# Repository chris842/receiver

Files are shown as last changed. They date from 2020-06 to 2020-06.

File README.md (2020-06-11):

# SDR Project
* Software-defined radio receiver, Engineering Electronics ii, Spring 2020
* Partners: Chrisner Garcesa and Andrew Nascimento

## Goal
The goal of this project was to design the schematic for a radio receiver and implement it on a PCB.

## Specifications
The specific goals to achieve given by our professor were as follows:  
* Minimum discernible signal of less than 1uV  
* Image rejection of over 48kHz of band greater than 30dB  
* Tunable range of frequencies greater than 48kHz  
* Band frequency greater than 540kHz  
* Spurious signals below 10uV  

Additional equipment we would have at our disposal would be the Arduino Nano Every

## Block Diagram
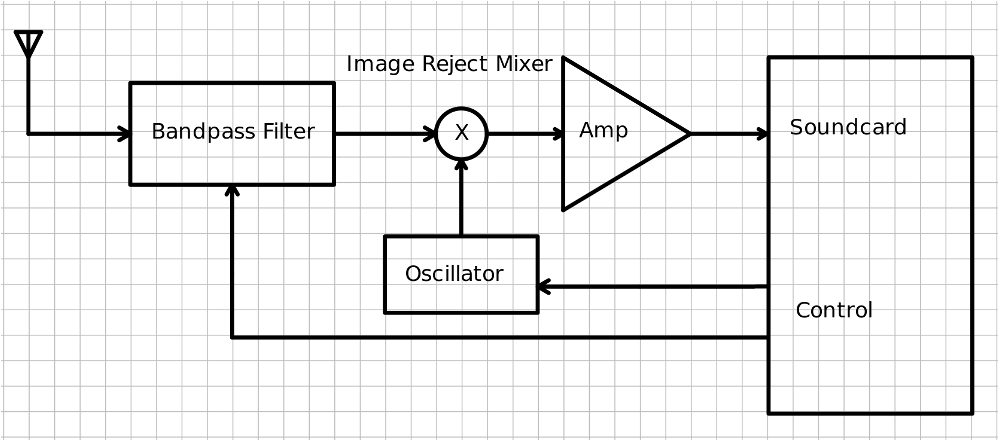
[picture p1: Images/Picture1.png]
Block Diagram
  
This is the general design we would follow in order to have a simple, working receiver. It would be our choice on how to implement each element of this design, however we often chose solutions that the professor suggested or other classmates were using as well, but adapted to our needs.

## Schematic
Here is a breakdown of our schematic:

### Bandpass-filter
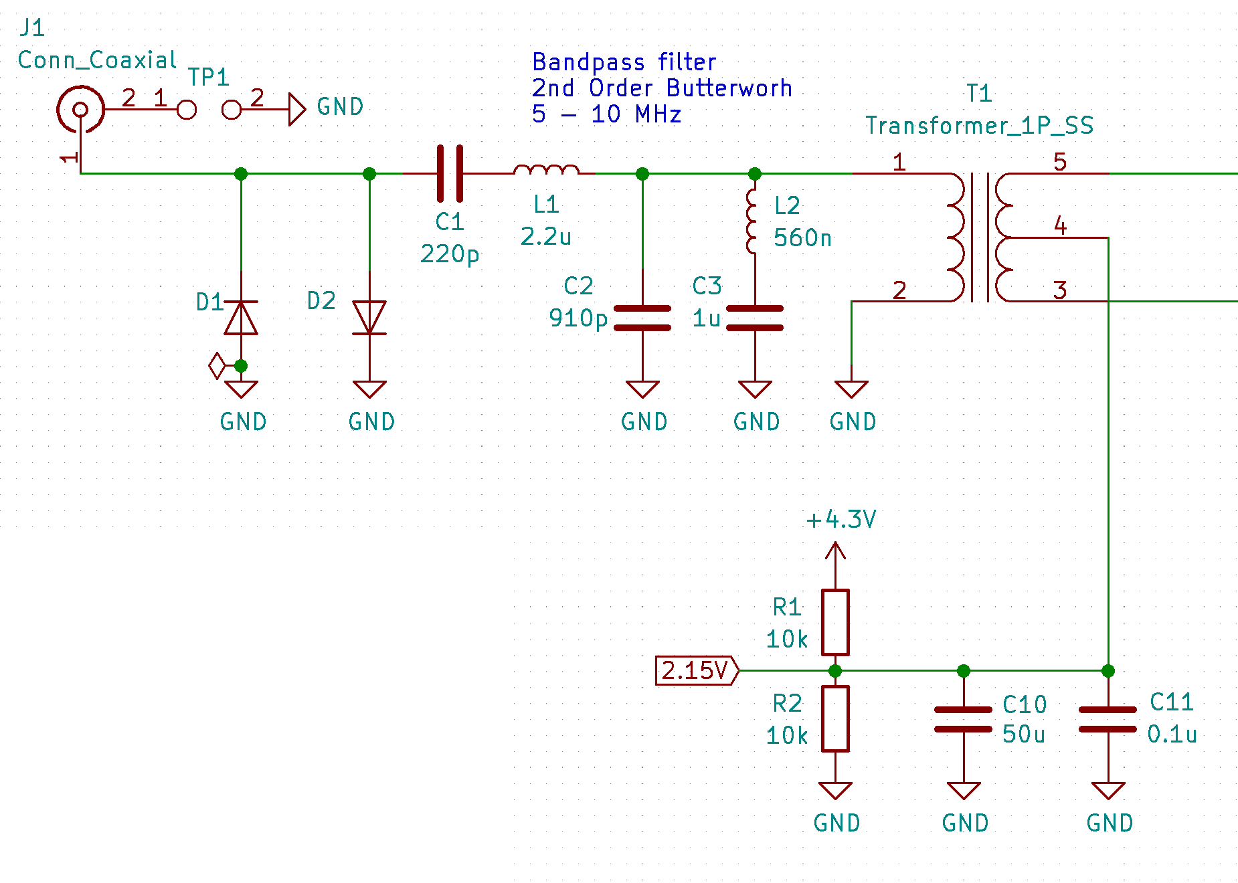
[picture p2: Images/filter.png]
Butterworth Filter
  
This part of the schematic is to filter our choice of frequencies to capture. We chose a range of 5-10MHz to listen to, so the incoming frequency is filtered through a 2nd order Butterworth filter. The transformer at the end sets the DC operating point of the incoming signal at 2.15V.

### Mixer
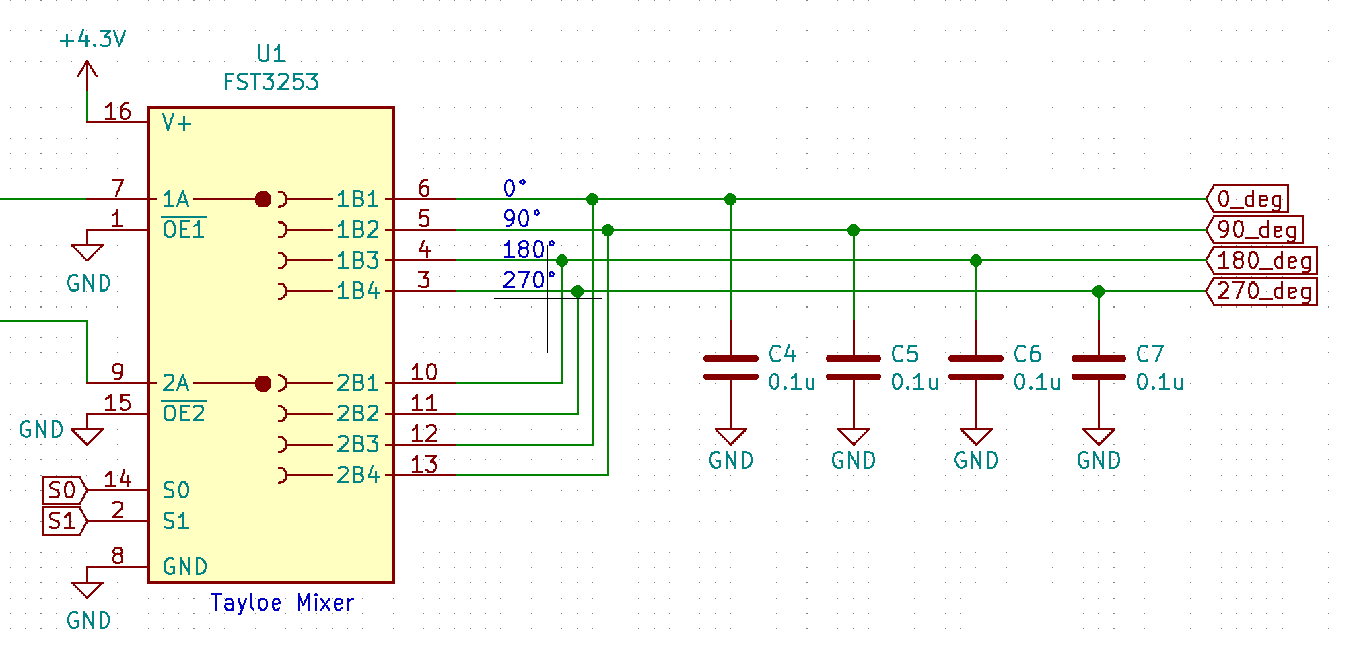
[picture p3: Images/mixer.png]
Tayloe Mixer
  
[This mixer was designed by Dan Tayloe]
(https://www.google.com/url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)

It is simple to implement, is low noise, and allows the bandwidth to be adjusted. The first part of this circuit, the multiplexer, breaks the incoming signal into four outputs, at 0˚, 90˚, 180˚, and 270˚. Then the op-amp, shown below, inverts the redundant sections of the wave and diffferentiates them with their same-phase pair, then outputs two signals, which he calls the In-Phase and Quadrature signals. The op-amp filters the output to the audio-frequency range of up to 25kHz.  
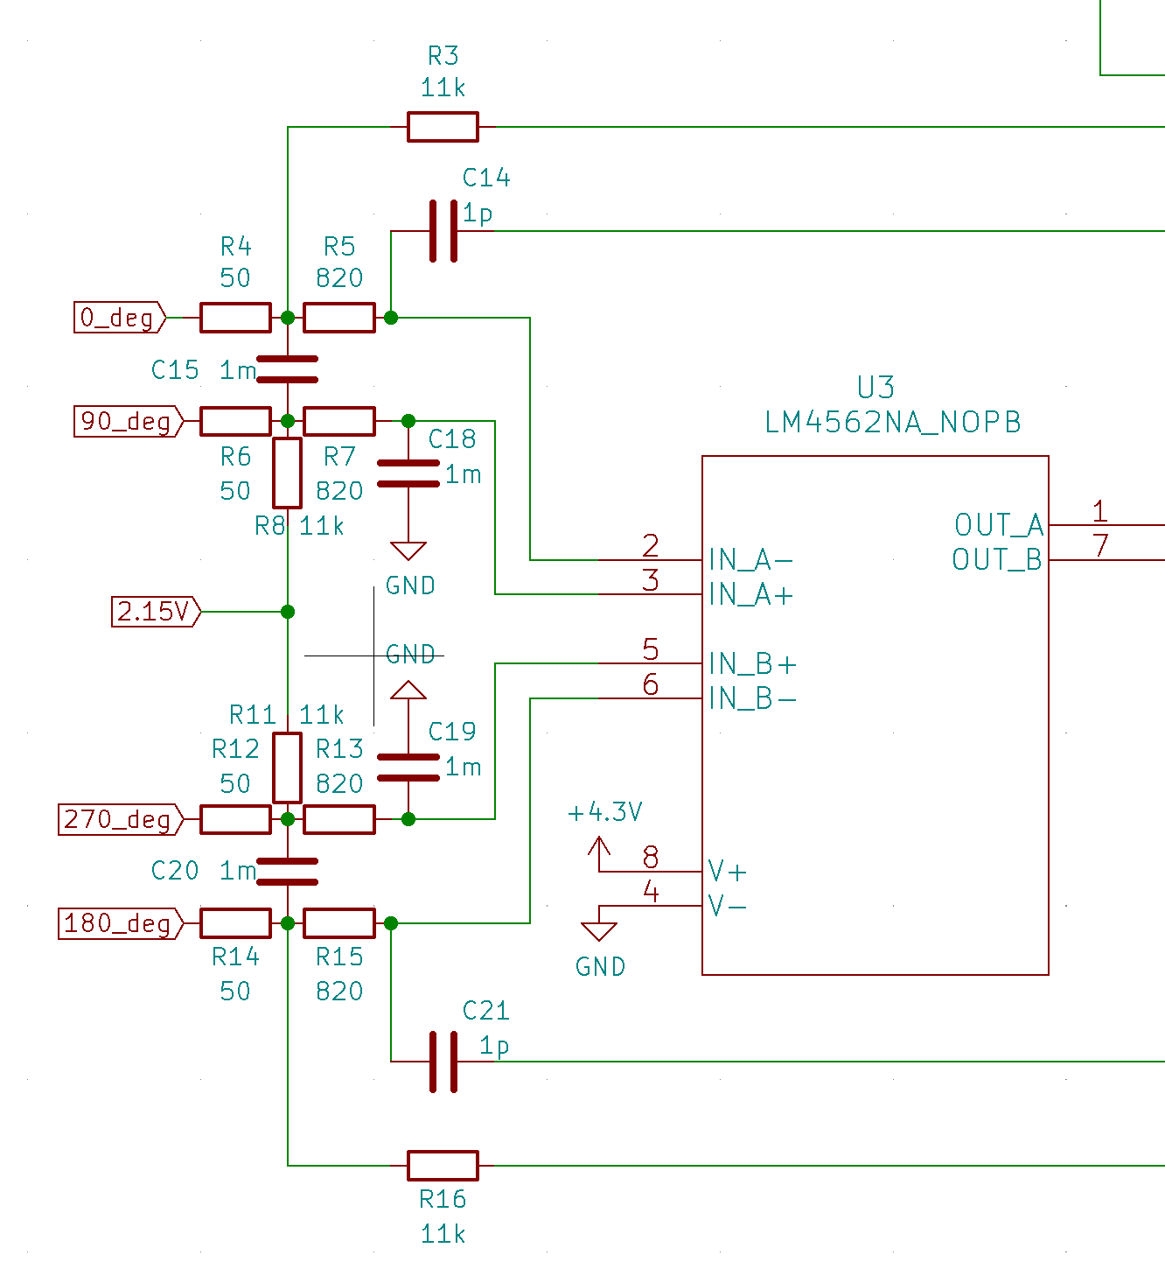
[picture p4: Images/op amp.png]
Op Amp


### Clock Generator and Johnson Counter
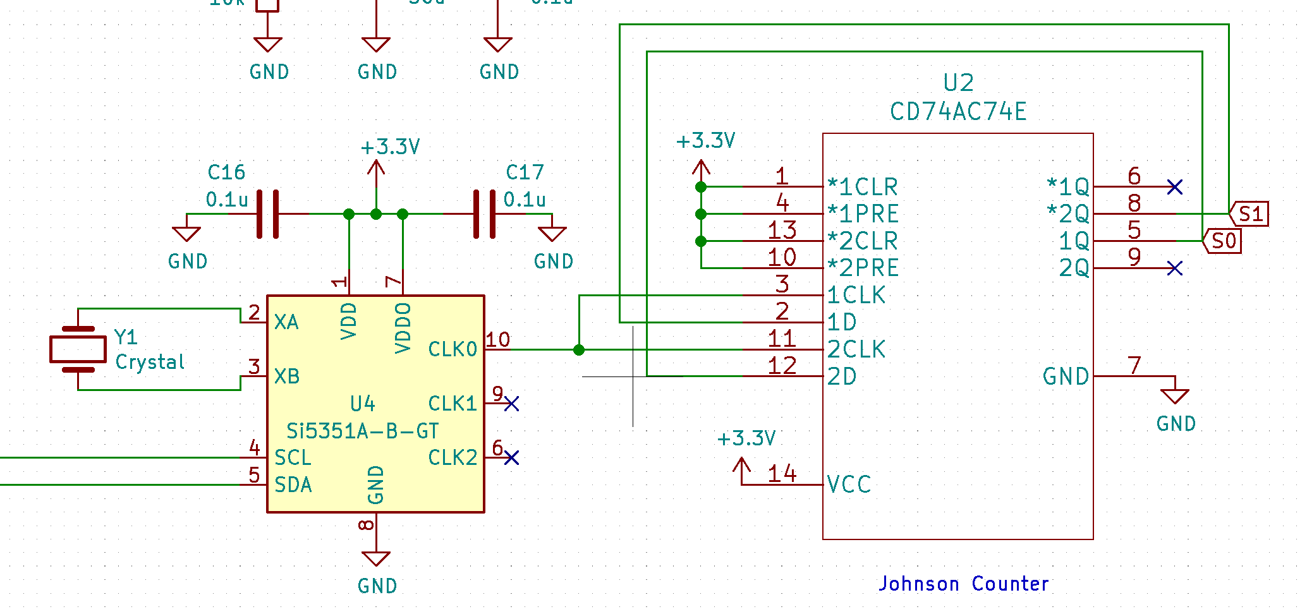
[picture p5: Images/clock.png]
Clock
  
The purpose of this circuit is to drive the multiplexer used in the Tayloe Mixer. The Johnson Counter arrangement of the flip-flops is used to activate the multiplexer switches, selecting the portion of the incoming wave to be inverted and differentiated. The switching frequency is set by an Arduino program.

### Voltage Smoother
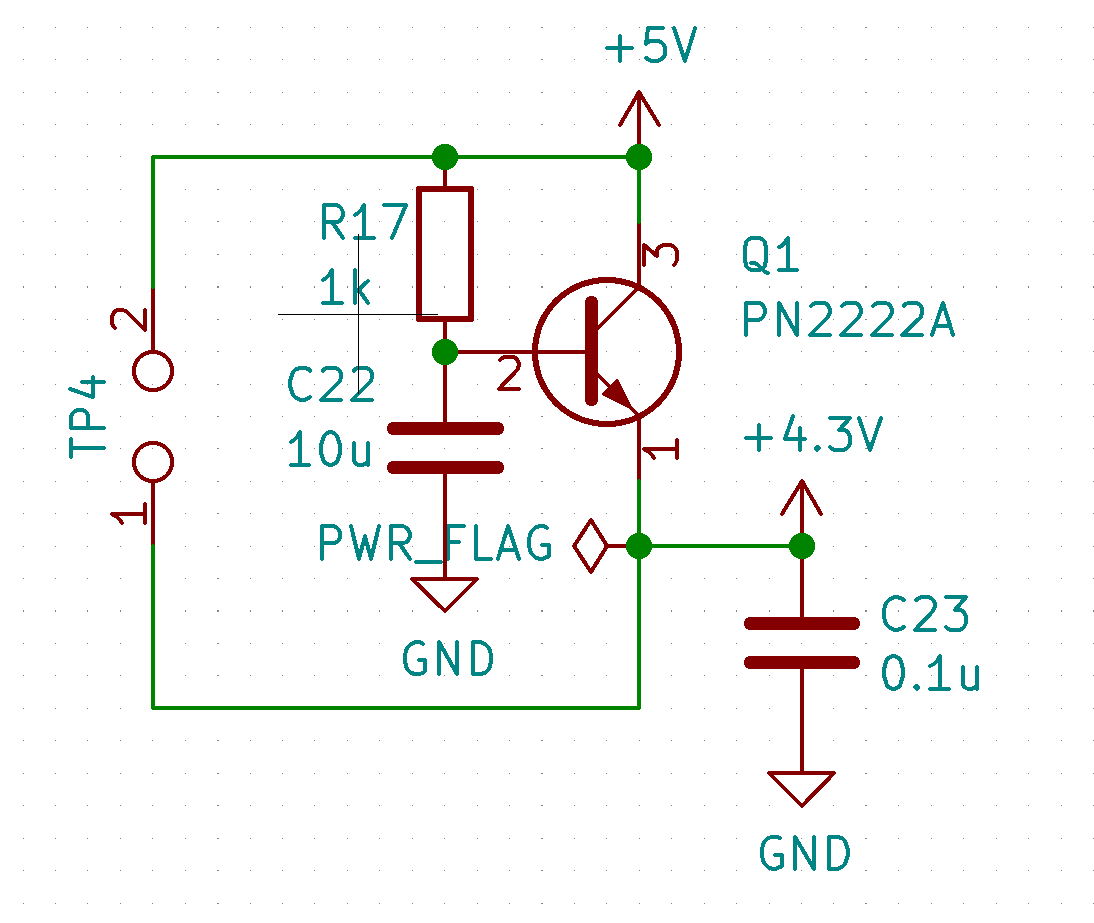
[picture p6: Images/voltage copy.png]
Voltage
  

Dr. Frohne designed this section of the schematic to provide a stable, ripple-free voltage source. It takes 5 volts from the Arduino and powers the multiplexer, op amp, and DC bias circuit.

### Complete Schematic
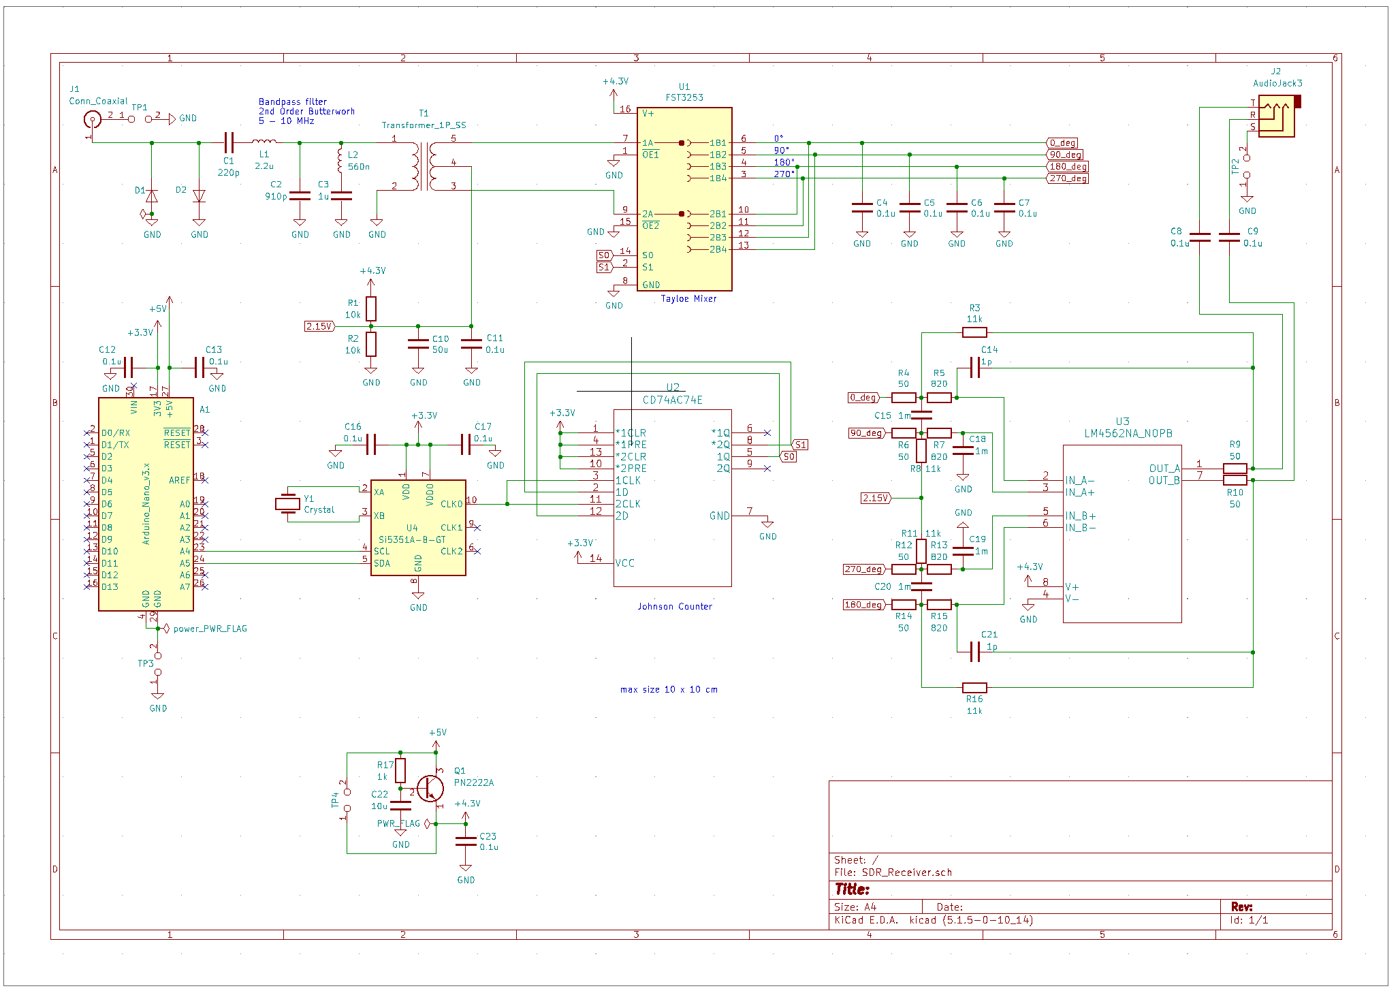
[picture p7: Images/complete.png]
Schematic
  

## PCB
### Board Schematic
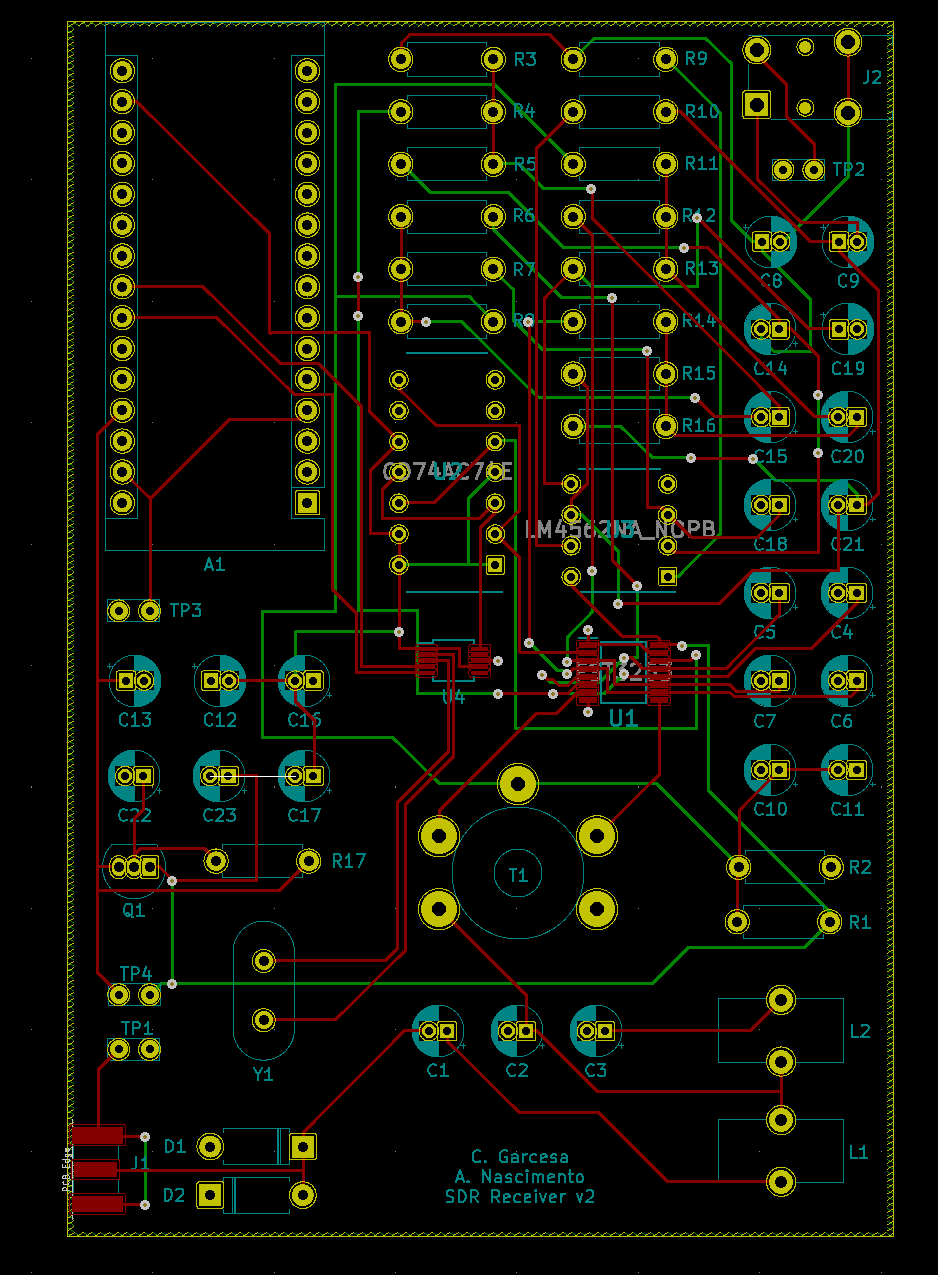
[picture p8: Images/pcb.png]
PCB
  
PCB design in KiCAD

### Board Render
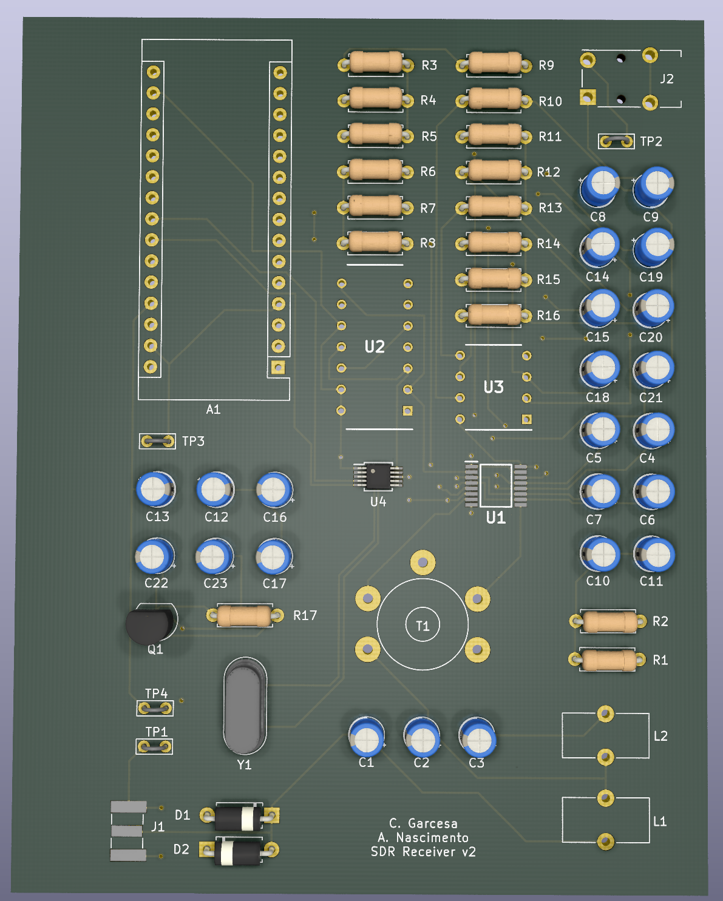
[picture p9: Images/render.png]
render
  

### Assembled Board
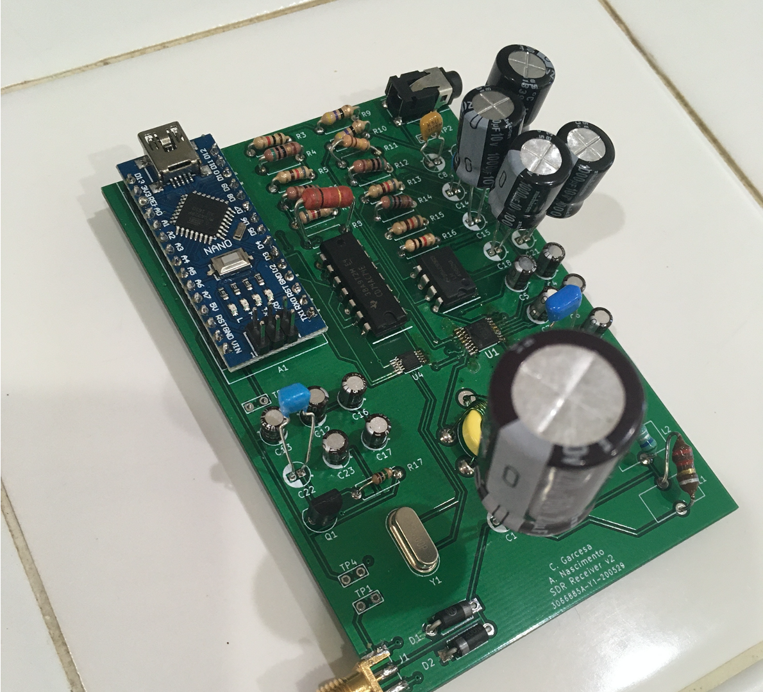
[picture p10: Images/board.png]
board
  

## Tests & Results
### Bandpass Filter
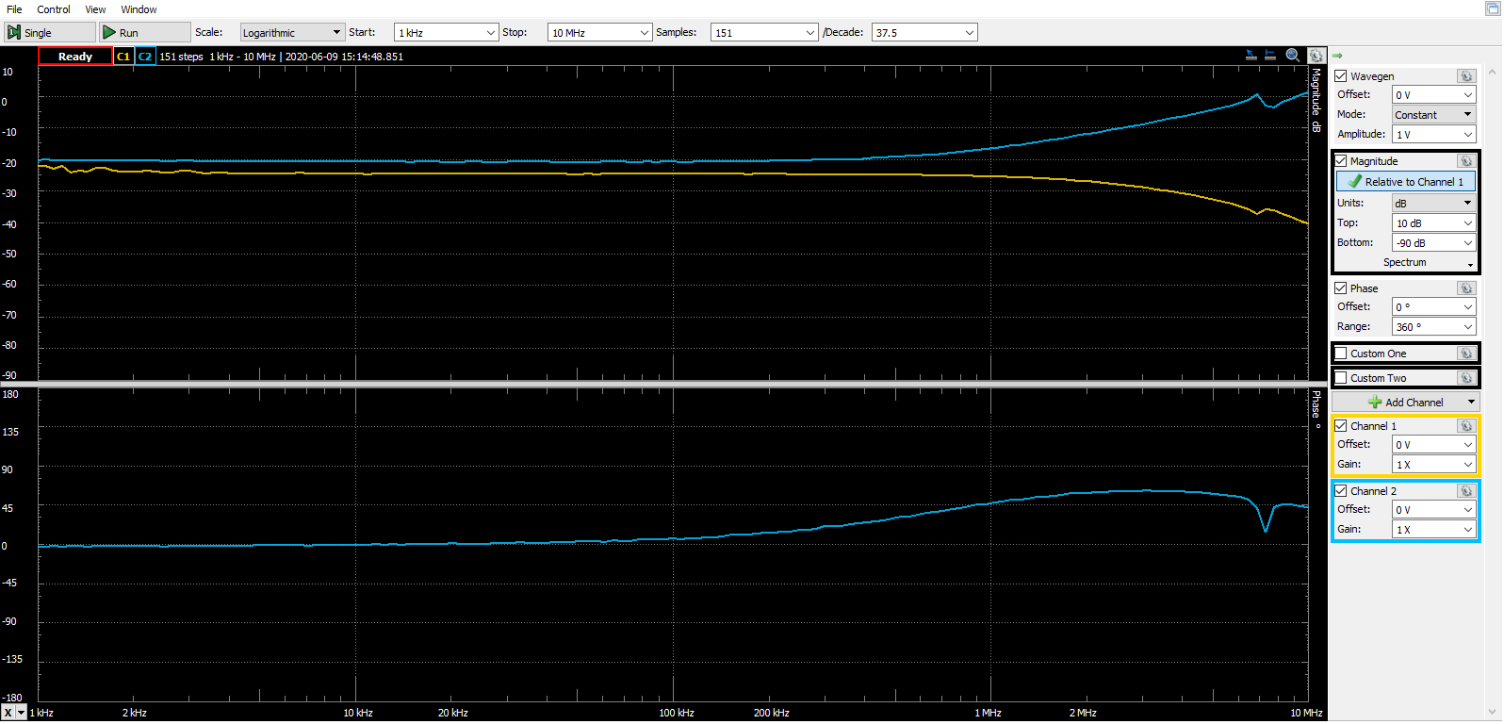
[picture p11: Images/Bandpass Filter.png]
bandpass
  
The bandpass filter seems to work as expected. There is attenuation up to around 5MHz, where our band begins. A 500mV test signal was used.

### Transformer
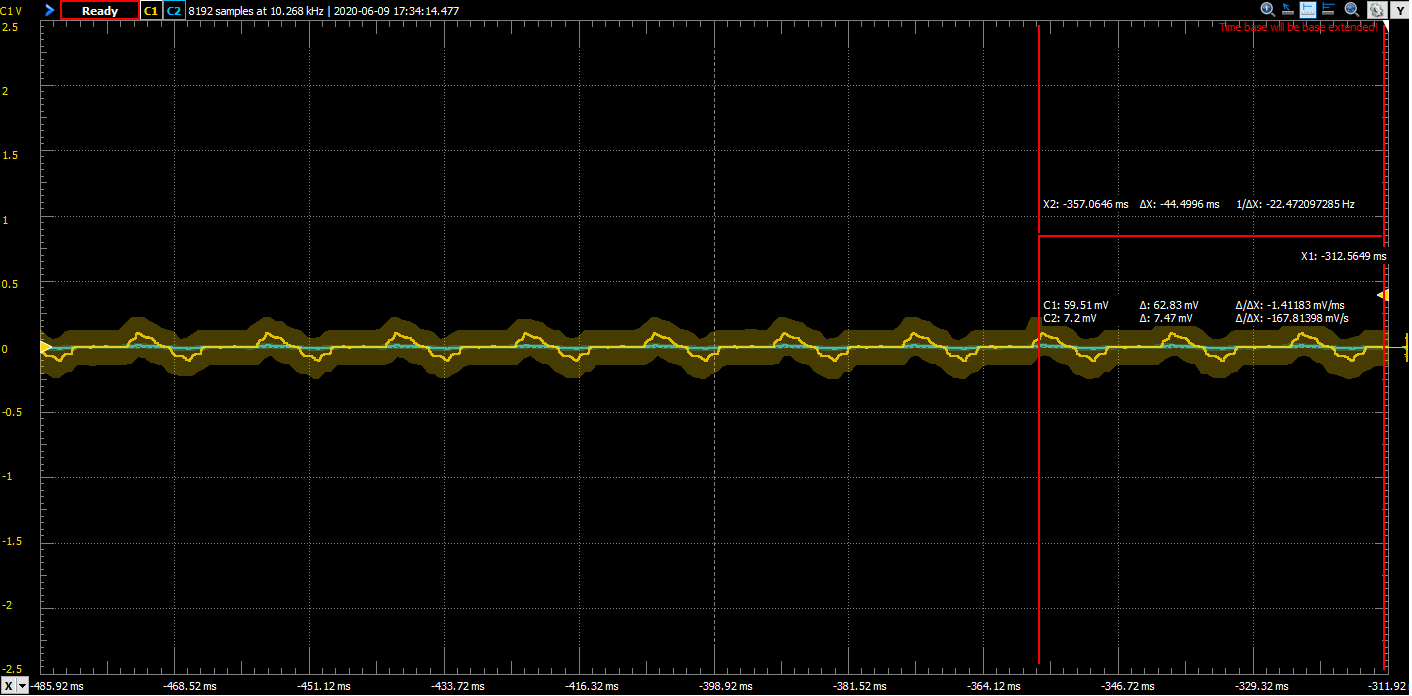
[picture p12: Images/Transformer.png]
transformer
  
Our initial winding configuration seemed to only produce noise. An updated winding configuration is shown further below.

### Tayloe Mixer
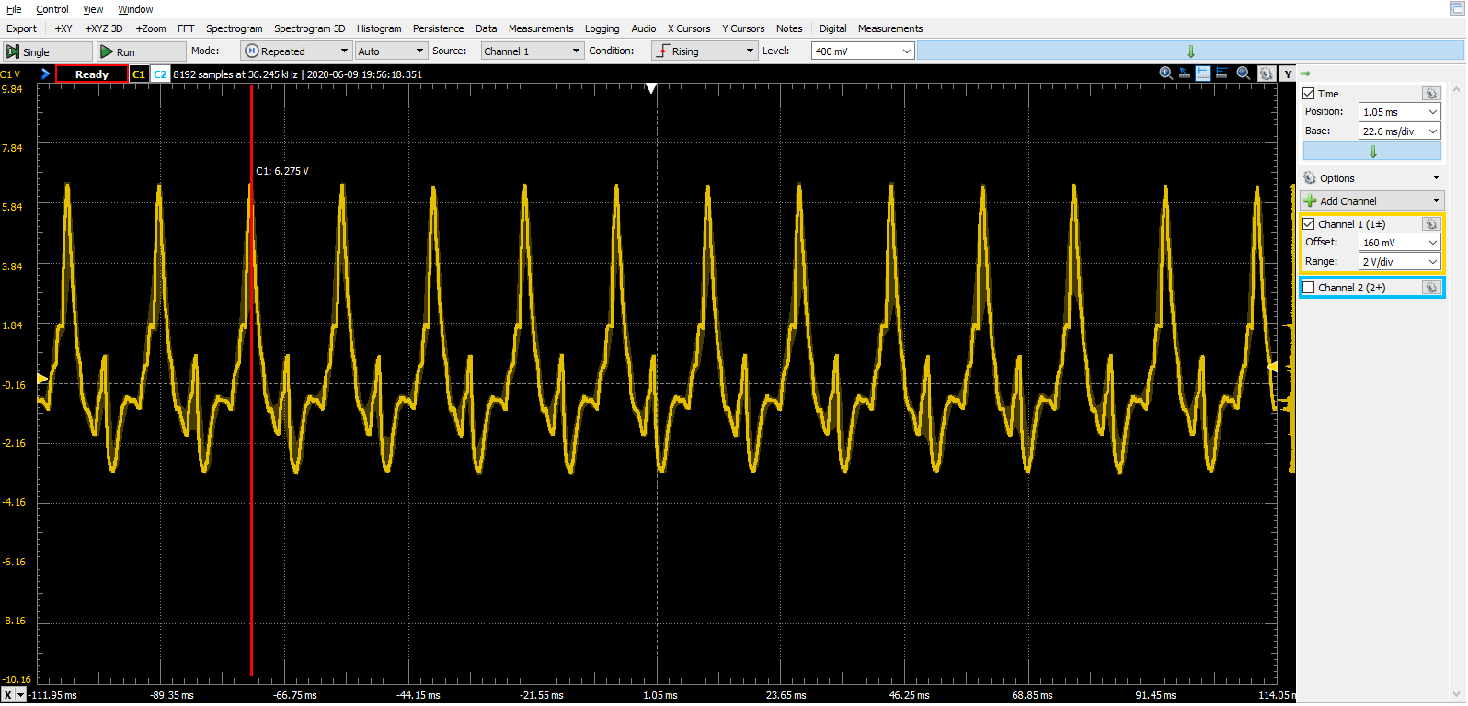
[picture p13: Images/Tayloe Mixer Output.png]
mixer
  
This is not the expected output of the Tayloe mixer. We expected to  a quadrant of a sine wave on each output. Since we cannot verify if the oscillator circuit is working properly, this error may be due to the oscillator.

### Op Amp
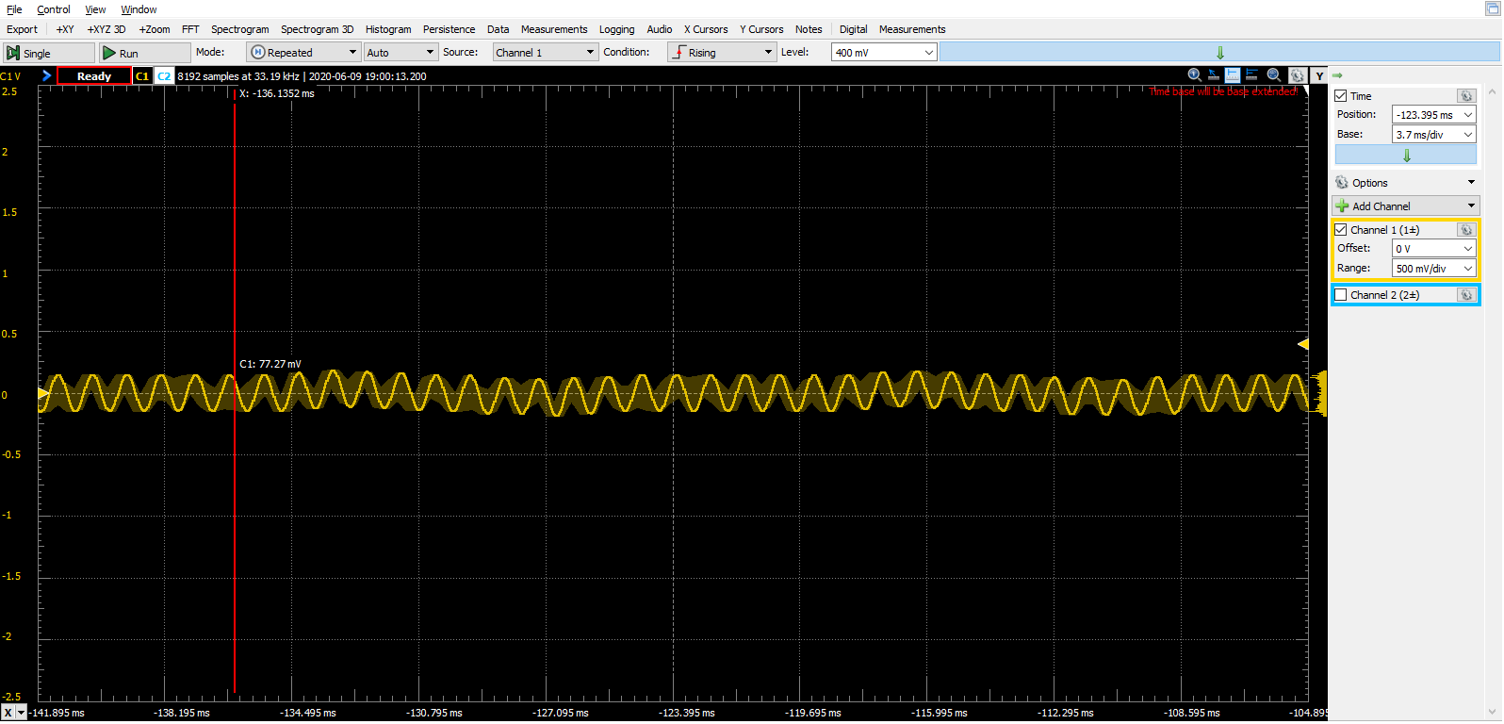
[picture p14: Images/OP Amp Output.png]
op amp
  
The op amp seems to be functioning. We can only verify if it works as intended when the Tayloe mixer is working.

### Arduino & Oscillator
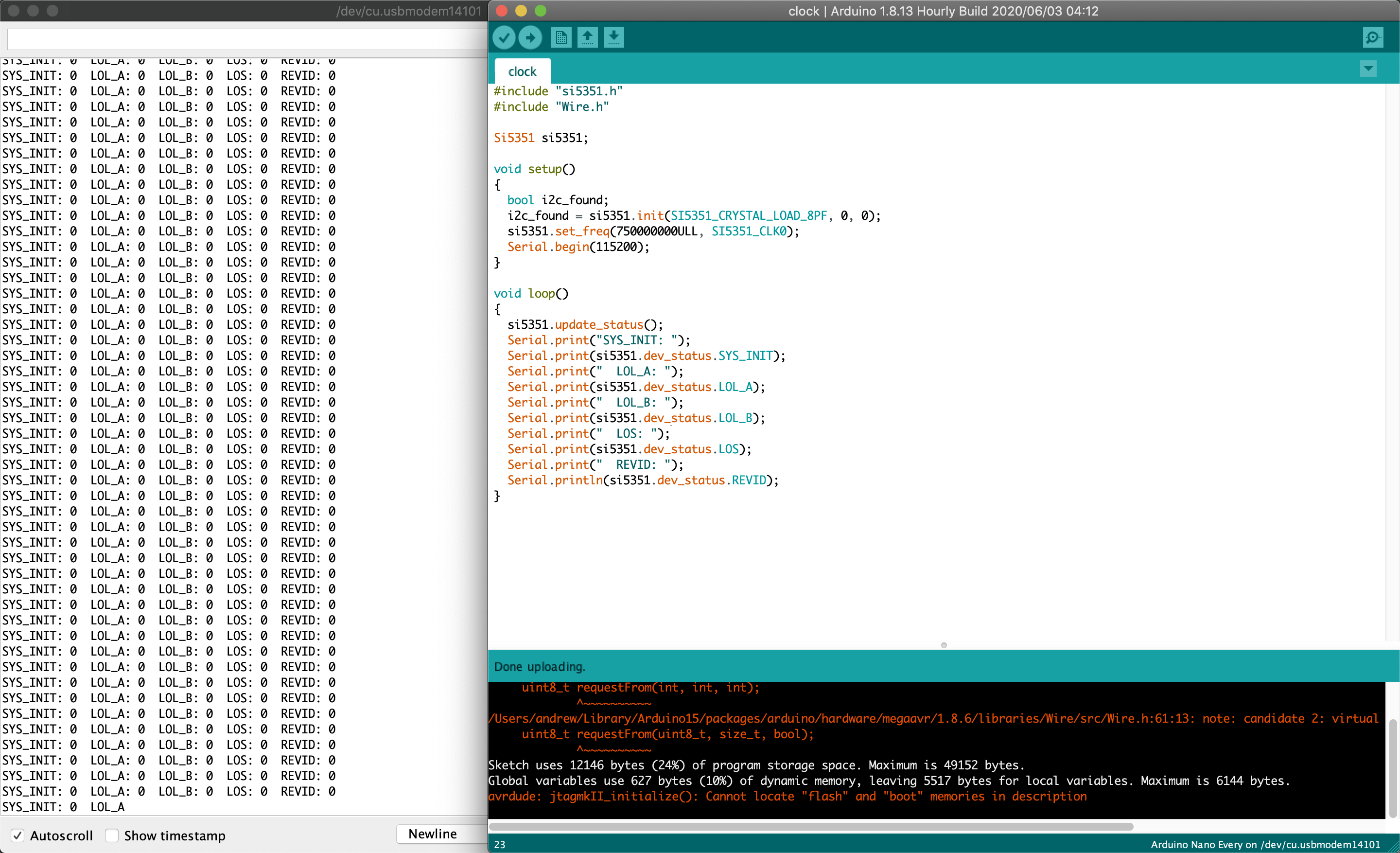
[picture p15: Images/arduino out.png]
arduino
  
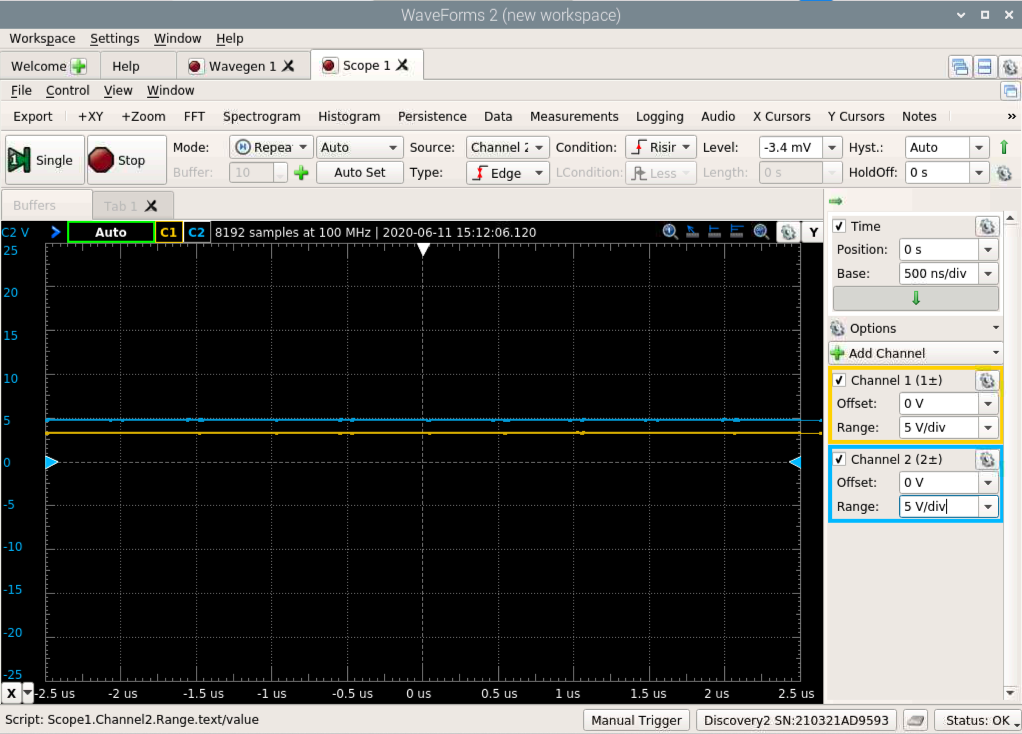
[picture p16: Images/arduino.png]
arduino
  
Arduino 5V and 3V3 signals appear as expected. Gauging by the serial output, the SDR program seems to be working, but we were not able to capture a signal on the SDA and SCL ports.

## Problems & Things to Fix
### Transformer
We tried a different configuration for the transformer, by winding 18 turns on the primary and 18 on the secondary, and placing a center tap from the 2.15V pad to the middle point of the transformer. We were able to capture a clean sine wave at the transformer input, but not the output. 

### Voltage Divider
We were able trace the 4.3V signal up to where it meets R1 at the voltage divider, but we did not see any voltage across R1 or R2. This can explain why the transformer secondary is not working.

### Tayloe Mixer
The Tayloe mixer is likely not working due to the transformer issue. Since 4.3V is being produced, the output is likely due to the lack of signal reaching the mixer.

### Oscillator
We assume the issue with the oscillator is due to the Arduino program, although it seems to be working fine. It may also be due to improperly placing the surface mount IC on the board. 

## Lessons Learned
### PCB Design
We learned how to design a PCB from start to finish using KiCAD.

### Test Points
Having more test points would make debugging the circuit much easier. We did not include enough test points on the board so it was difficult to get measurements in certain places, and that made it harder to narrow down where issues were originating.

### Trial & Error
While it is important to simulate as much as possible so that a working design is achieved when the board is printed, some things were only able to be debugged when we put the circuit together. Simulation also doesn't account for our personal errors and mishaps, so having extra parts for a future project is important in case we damage parts.

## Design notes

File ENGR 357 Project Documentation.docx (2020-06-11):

ENGR 357

SDR Project

Chrisner Garcesa

Andrew Nascimento

June 10, 2020

Project Description

The purpose of this project was to build a software defined radio, to which we decided that it would operate from 5 to 10 MHz. To control the device, we will be using a. Arduino Nano, and we will use a program provided to control the Arduino. We also had to build an attenuator, which would help with the SDR device.

Circuit Description

When looking up circuit designs, there was one that I found that I thought would be helpful. Our design wasn’t entirely based on it, but it helped serve as a guide on how we should go about designing the board. When I went about researching for the project, there was one site (https://www.arrl.org/files/file/Technology/tis/info/pdf/020708qex013.pdf) that I found to be useful. This is where I got the basic layout for the project, and more details will be discussed later on.

Differential Op Amp

Tayloe Mixer

Bandpass Filter

Oscillator

Johnson Counter

Arduino Nano

The signal coming in will have to go through the bandpass filter, to which we decided it should operate around 5 to 10 MHz. In order to get the values to get that range, we used an online calculator (https://rf-tools.com/lc-filter/) to get the desired values. The type of bandpass filter we decided to use was a Buttersworth, series first, 3rd order bandpass filter. For the Tayloe Mixer, there were a couple of other mux’s that we had gone through before getting to the FST3253. When designing this, it should ideally range from 0°, 90°, 180°, and 270°. There was also the oscillator, and to operate that, we used a Si5351, which in turn would be powered by the Arduino nano. Before that, we have the Johnson counter. For this stage, we chose a CD74A74E flip flop. We had originally gone with a different flip flop, but we went with the latter due to it being a bit faster than the original one we chose. The differential Op Amp was something that was implemented later on in the design phase, right before we had to turn the schematic. I had originally had just a low pass filter at the end before the signal went to the audio jack, but Andrew had added the differential op amp to help with the design.

Software

One of the most obvious parts of the board that needed software was the Arduino Nano. For this, we needed to download Arduino IDE and the code we used to test the oscillator and the clock was taken from Frohne’s github (https://github.com/frohro/IQ_SDR/tree/master/Quisk). Other bits of software we used was Python (https://www.python.org/), WaveForms (https://store.digilentinc.com/waveforms-download-only/), and Quisk (https://james.ahlstrom.name/quisk/), which would’ve helped us with testing when our boards were built.

Build Instructions

Due to the nature of this project, the board had to be built in 4 main stages. They can be done in the following order:

1. Bandpass filter
2. Tayloe Mixer
3. Johnson Counter
4. Differential Amplifier

A good place to start though is by soldering on the IC chips, since they are the most difficult to put on the board. I would suggest putting a bit of solder on one of the places where the pins should be, and after it settles, put the IC chip in its place (make sure it’s oriented correctly). Using the soldering iron, heat up the place where the solder is and hold the IC in place. If done correctly, the IC chip should be set in place, and then the rest of the pins can be filled with solder (make sure just to put a little bit and not too much, otherwise the pins may end up being connected together). After the IC’s have been placed in their places, the next thing to do is to build each stage and testing each one separately (however, I made the mistake of not doing that, so testing became a little bit difficult to do, but not impossible. Highly recommended building in stages). After each stage has been built and tested, you can move on to the next one and so on, until each stage has been built.

Test Results

The test results for the project are a bit mixed. There were some components that did work, and there were other areas where it did not work out as intended. One of the things that had worked out as intended was the bandpass filter, which was probably the easiest part to test out. The other stage that had worked out was the differential op amp. When I tested this part, it was recommended that I take out two resistors (R4 and R6), and I hooked up two probes at those resistors and connected a single probe to one of the capacitors at the output. The two probes connected to the resistors were connected to the wave generator, and the single probe should be the one that will measure the output. When I tested this, I had put in a small signal, one that was around 500 mV. For the output, I thought the signal coming out of the capacitors was fairly good, though I will note that the sinewave output was a bit smaller than the input.

What didn’t work was the Tayloe Mixer, the Johnson Counter, the transformer, and the crystal oscillator. When I had tested the transformer, I had connected a probe at the output of the transformer, which could either be pins 5 or 3. I had also placed probes at the beginning of the bandpass filter, which were connected to the two diodes. After running a signal through the bandpass filter and the transformer, the output of the transformer came out to be a bit messy. The output signal somewhat resembled a sine wave, but it looked a bit rough and sporadic. The next thing that I had tested was the Tayloe mixer, and the signal that came out more or less the same as the transformer. I had even tested it separately by placing two probes at the beginning of the Tayloe mixer and measured it at the end, and the signal appeared to be just as messy. The last thing that I had tried testing was the Johnson Counter and the Crystal oscillator. However, this required using the code needed for the Arduino Nano, and the problem with this was the Arduino IDE kept crashing every time I tried opening it (I had tried to install older versions, but those versions also kept crashing on startup). At this point, it was fairly late, so I couldn’t test any further.


Bandpass Filter


Differential Op Amp


Transformer Output


Tayloe Mixer Output

Considerations for future uses

There were a couple of things that I had thought of for trying to fix the device. So far, the only things that I think may work as intended are the Bandpass filter and the Differential Op Amp. However, there is a lot more work to do with the other parts of the board. Here are a couple of ideas on how to fix:

1. Fixing the transformer: the transformer turns ratio may be responsible for this. From how it was built, it was a step-down transformer, so probably changing it to a step-up transformer may help. Another thing that will have to be taken into consideration is the turns ratio. Due to time constraints, I had little time to calculate the turns ratio, so I ended up using an online calculator to determine the turns ratio (the online calculator required input and output impedances, where I needed the output impedance to determine the turns ratio, which I think wasn’t correct).
2. Reconfiguring the Tayloe Mixer and Crystal Oscillator: I also have reason to believe that both these stages would not work out as well, even if the I got the code working for them. Some things that I may do is try to simulate these stages again, but I will try to do it carefully. Another issue may be how I soldered the IC chips. I had soldered these chips by hand, and I had made sure that each pin was not somehow connected. With that said, there may be some pins that are accidentally connected, so I may try a different method of soldering the next time around. Lastly, the crystal oscillator may also potentially be a problem, so I may have a closer look on how to fix that part

Conclusion

After building and testing the board, there are still a lot more things to fix in order to get this thing working. With that said, I will try to work on this more in the future to (hopefully) get it into a working state. One of the stages that I will try to focus a bit more on detail is the Tayloe Mixer and the Johnson counter. I believe these are the more crucial parts of the board, and if I can get this working, I think that it’ll be easier to work with the rest of the board. The other stages and components should be fairly easy to work with, so I’m not too worried about the other stages.

Along with this project, I think that I had learned more about how to use KiCAD and how to design a PCB and what to take into consideration. With this board, there were some parts that were hard to solder on, so knowing that I will have to take into consideration who will be building the board, and how to make it easy as possible to build.

With that said, I will try to work on this project in the future. I think that it’ll be interesting to have this device actually work, and I will try to do more research on how to debug and fix this device.

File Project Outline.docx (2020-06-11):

Chrisner Garcesa

Rob Frohne

ENGR 357L

7 May 2020

Electronics II: Project Outline

1. Have values for resistors and capacitors figured at least before the board arrives
  a. Some of the parts on the board have not yet been figured out, so I will have to work with my partner to have that sorted out
  b. Primarily work on this part from 5/15/20 – 5/17/20.
2. Solder on parts onto board
  a. Solder on the hardest parts (surface mount parts) on the board
    i. Watch some videos on how to carefully solder on surface mount (i.e. IC chips)
      1. If the IC chips are being soldered on, make sure they are correctly oriented in place
  b. Solder on through hole parts (i.e. resistors, capacitors, diodes, etc.)
3. Before everything is put on the board, test each individual circuit on the board
  a. While soldering, keep in mind that the circuits on the board must be built in stages
  b. Stages:
    i. Bandpass Filter
    ii. Tayloe Mixer
    iii. Lowpass Filter
  c. After finishing each stage, make some tests and move on if it’s working as intended.
    i. If the stage does not work correctly, check, and see if some of the parts (hopefully not the surface mount parts) are placed on properly
4. Have the whole entire board built and make tests
  a. After the whole board has been built and has been tested thoroughly, send in a signal and check to see if it’s working as intended

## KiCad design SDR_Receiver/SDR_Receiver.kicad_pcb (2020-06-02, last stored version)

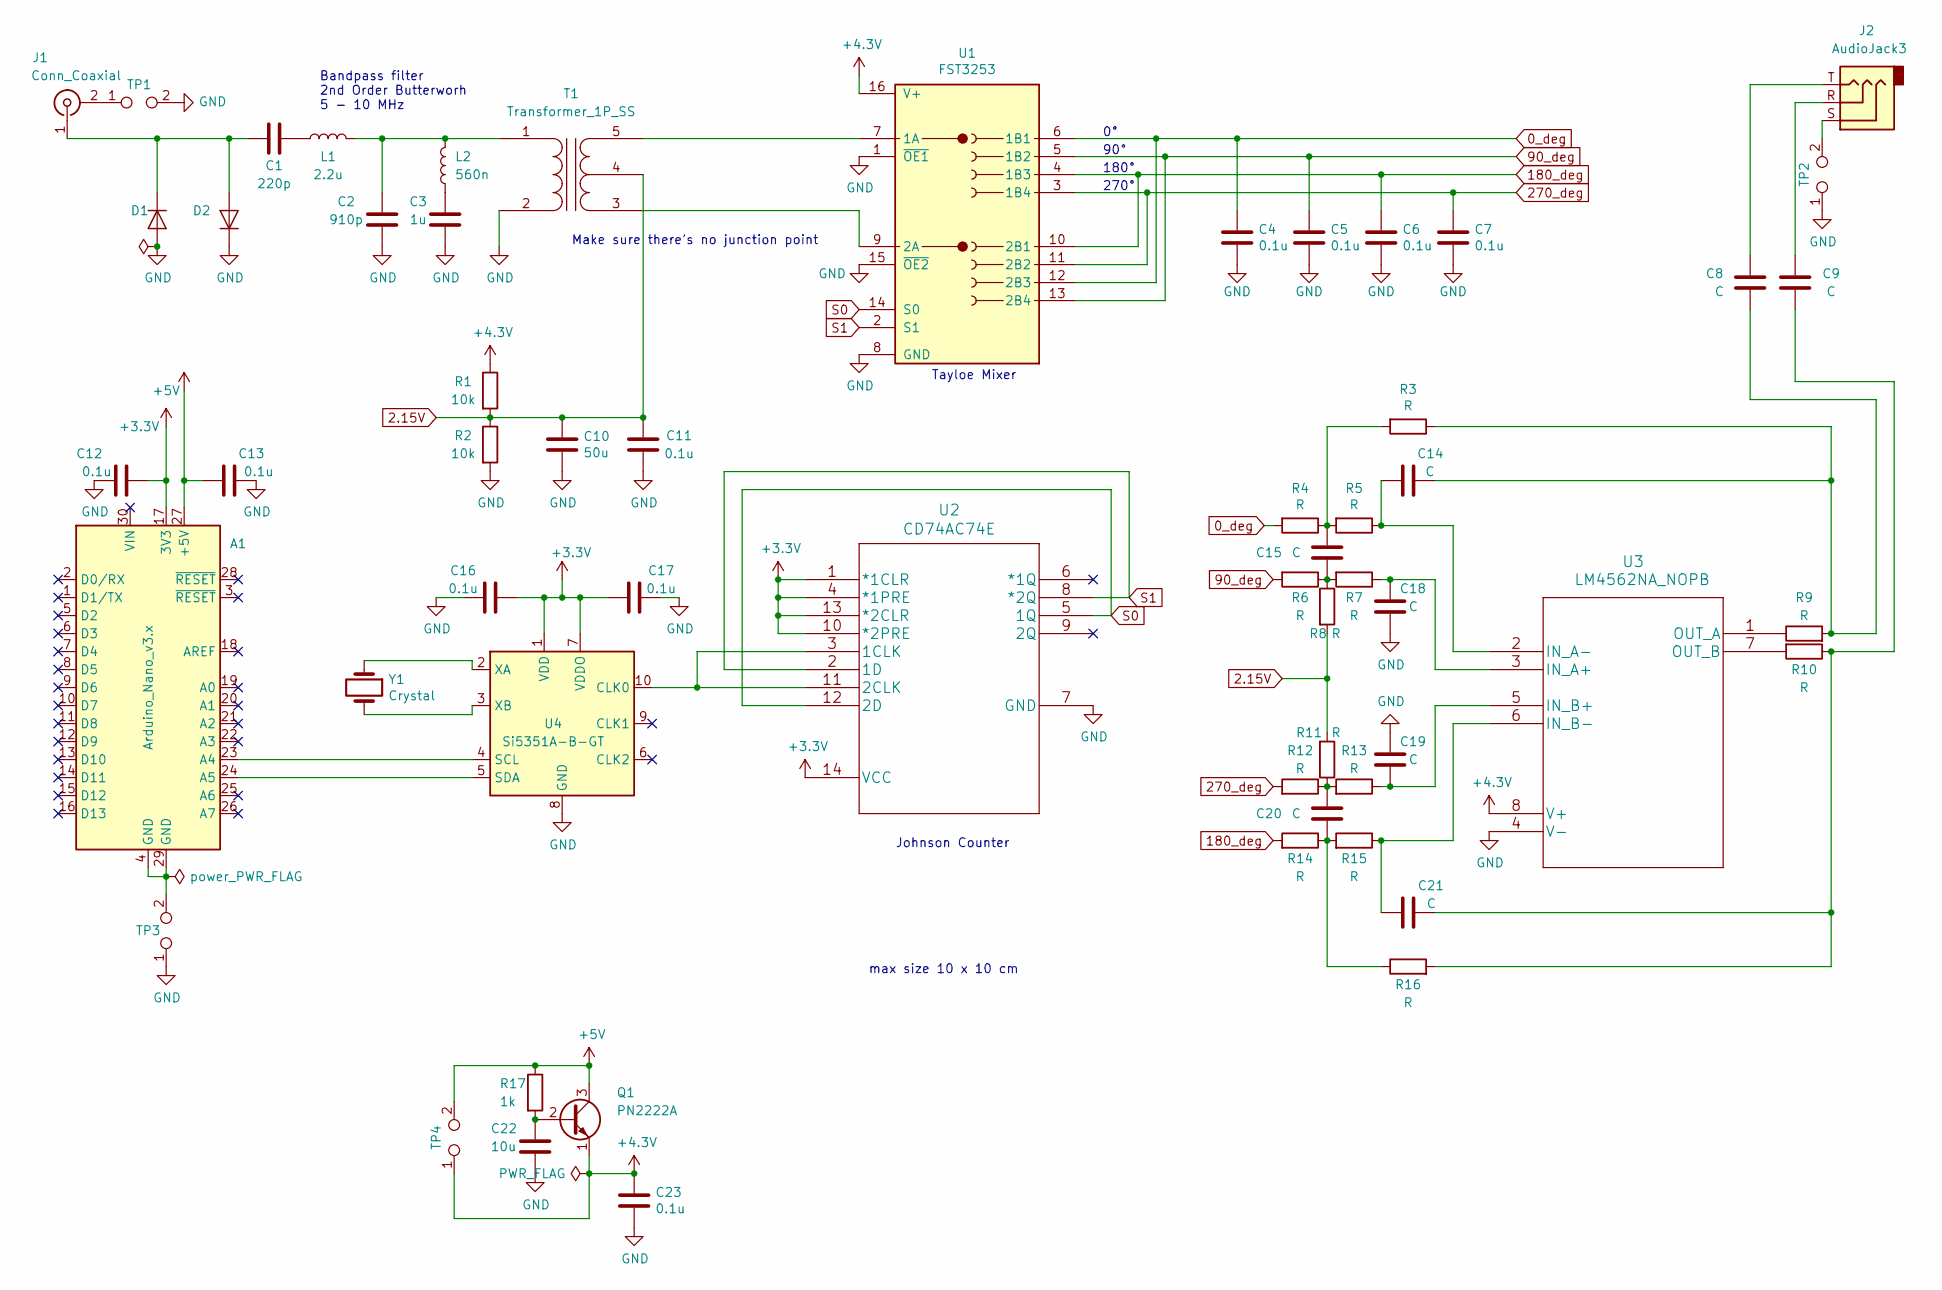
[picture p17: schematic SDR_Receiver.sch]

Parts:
A1: Arduino_Nano_v3.x; Arduino_Nano
C1: 220p; CP_Radial_D4.0mm_P1.50mm
C2: 910p; CP_Radial_D4.0mm_P1.50mm
C3: 1u; CP_Radial_D4.0mm_P1.50mm
C4, C5, C6, C7, C11, C12, C13, C16, C17, C23: 0.1u; CP_Radial_D4.0mm_P1.50mm
C8, C9, C14, C15, C18, C19, C20, C21: C; CP_Radial_D4.0mm_P1.50mm
C10: 50u; CP_Radial_D4.0mm_P1.50mm
C22: 10u; CP_Radial_D4.0mm_P1.50mm
D1, D2: D; D_A-405_P7.62mm_Horizontal
J1: Conn_Coaxial; SMA_Samtec_SMA-J-P-X-ST-EM1_EdgeMount
J2: AudioJack3; Jack_3.5mm_Switronic_ST-005-G_horizontal
L1: 2.2u; L_Toroid_Vertical_L10.0mm_W5.0mm_P5.08mm
L2: 560n; L_Toroid_Vertical_L10.0mm_W5.0mm_P5.08mm
Q1: PN2222A; TO-92_Inline
R1, R2: 10k; R_Axial_DIN0207_L6.3mm_D2.5mm_P7.62mm_Horizontal
R3, R4, R5, R6, R7, R8, R9, R10, R11, R12, R13, R14, R15, R16: R; R_Axial_DIN0207_L6.3mm_D2.5mm_P7.62mm_Horizontal
R17: 1k; R_Axial_DIN0207_L6.3mm_D2.5mm_P7.62mm_Horizontal
T1: Transformer_1P_SS; Transformer_Toroid_Tapped_Horizontal_D10.5mm_Amidon-T37
TP1, TP2, TP3, TP4: TestPoint_2Pole; TestPoint_Bridge_Pitch2.54mm_Drill0.7mm
U1: FST3253; SOP65P640X110-16N
U2: CD74AC74E; DIP794W53P254L1930H508Q14N
U3: LM4562NA_NOPB; DIP794W53P254L959H508Q8N
U4: Si5351A-B-GT; MSOP-10_3x3mm_P0.5mm
Y1: Crystal; Crystal_HC49-4H_Vertical

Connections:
0_deg: C4.1, R4.2, U1.6 (1B1), U1.12 (2B3)
2.15V: C10.1, C11.2, R1.2, R2.1, R8.2, R11.2, T1.4 (SC)
90_deg: C5.1, R6.2, U1.5 (1B2), U1.13 (2B4)
180_deg: C6.1, R14.2, U1.4 (1B3), U1.10 (2B1)
270_deg: C7.1, R12.2, U1.3 (1B4), U1.11 (2B2)
+3V3: A1.17 (3V3), C12.2, C16.2, C17.1, U2.1 (*1CLR), U2.4 (*1PRE), U2.10 (*2PRE), U2.13 (*2CLR), U2.14 (VCC), U4.1 (VDD), U4.7 (VDDO)
+4V: C23.1, Q1.1 (E), R1.1, TP4.1, U1.16 (V+), U3.8 (V+)
+5V: A1.27 (+5V), C13.1, Q1.3 (C), R17.1, TP4.2
unnamed: A1.23 (A4), U4.4 (SCL)
unnamed: A1.24 (A5), U4.5 (SDA)
unnamed: A1.4 (GND), A1.29 (GND), TP3.2
unnamed: C1.1, L1.1
unnamed: C1.2, D1.1 (K), D2.2 (A), J1.1 (In)
unnamed: C2.1, L1.2, L2.1, T1.1 (AA)
unnamed: C3.1, L2.2
unnamed: C8.2, J2.T
unnamed: C9.2, J2.R
unnamed: C14.1, R5.1, U3.2 (IN_A-)
unnamed: C8.1, C14.2, R3.1, R9.2
unnamed: C15.1, R3.2, R4.1, R5.2
unnamed: C15.2, R6.1, R7.2, R8.1
unnamed: C18.1, R7.1, U3.3 (IN_A+)
unnamed: C19.1, R13.1, U3.5 (IN_B+)
unnamed: C20.1, R14.1, R15.2, R16.1
unnamed: C20.2, R11.1, R12.1, R13.2
unnamed: C9.1, C21.1, R10.1, R16.2
unnamed: C21.2, R15.1, U3.6 (IN_B-)
unnamed: C22.1, Q1.2 (B), R17.2
unnamed: J1.2 (Ext), TP1.1
unnamed: J2.S, TP2.2
unnamed: R9.1, U3.1 (OUT_A)
unnamed: R10.2, U3.7 (OUT_B)
unnamed: T1.3 (SA), U1.9 (2A)
unnamed: T1.5 (SB), U1.7 (1A)
unnamed: U2.3 (1CLK), U2.11 (2CLK), U4.10 (CLK0)
unnamed: U4.2 (XA), Y1.1
unnamed: U4.3 (XB), Y1.2
S0: U1.14 (S0), U2.5 (1Q), U2.12 (2D)
S1: U1.2 (S1), U2.2 (1D), U2.8 (*2Q)

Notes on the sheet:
Bandpass filter 2nd Order Butterworh 5 - 10 MHz
270°
180°
90°
Tayloe Mixer
Johnson Counter
Make sure there’s no junction point
max size 10 x 10 cm

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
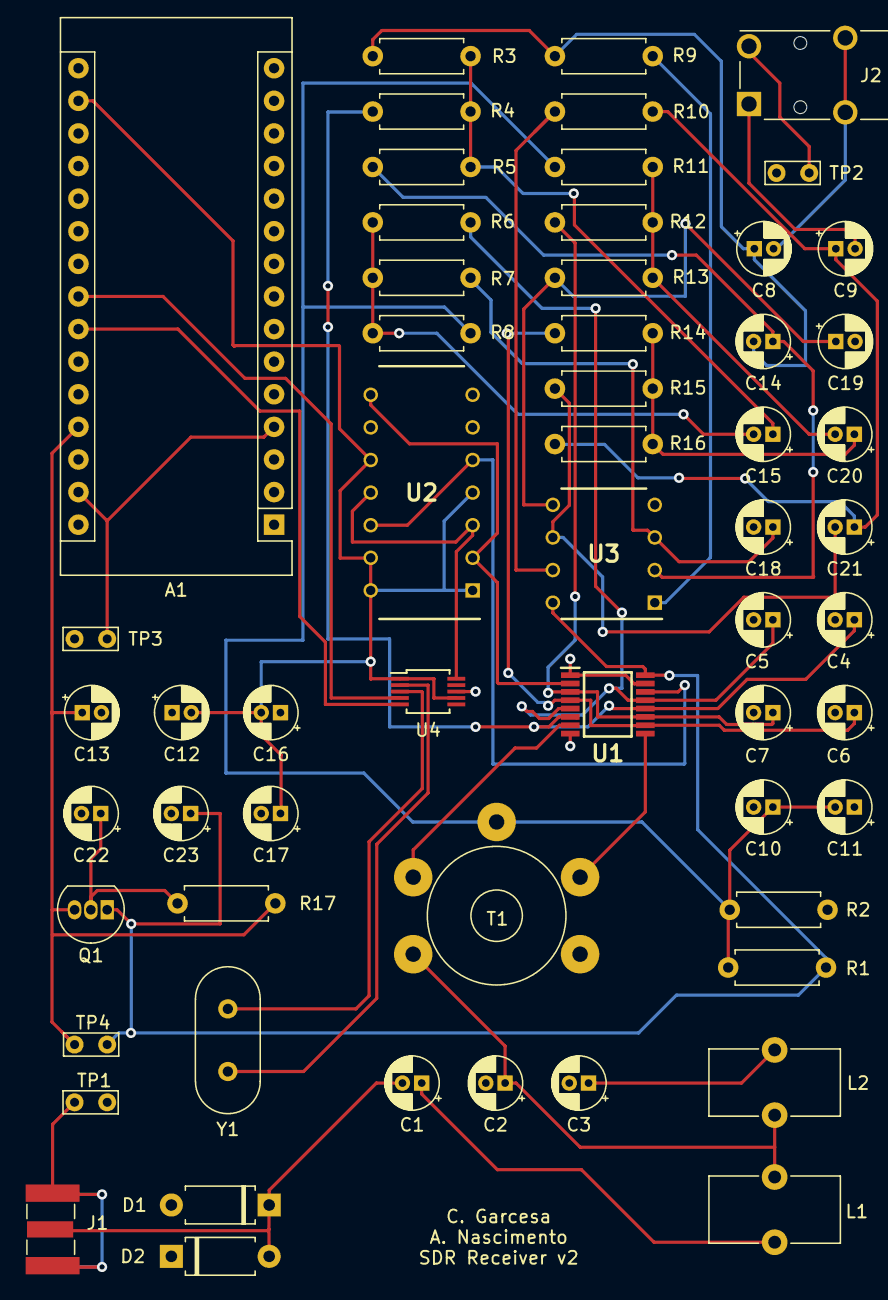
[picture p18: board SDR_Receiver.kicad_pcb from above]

Board: 2 copper layers, 58 parts (0 on the bottom side), 40 nets.
